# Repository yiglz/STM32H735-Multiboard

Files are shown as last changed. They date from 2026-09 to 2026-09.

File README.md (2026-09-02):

# STM32H735 Multiboard

Custom STM32H7-based embedded hardware platform designed for mixed-signal measurement and high-speed interfacing.

## Overview

This board combines a general-purpose embedded platform (Ethernet, USB HS, CAN-FD, local storage) with a precision analog front-end capable of impedance/frequency-response measurement. The idea was to have something that can act both as a data acquisition node and a small bench instrument on the same board.

## Features

- STM32H735 (Cortex-M7) MCU, 0.65mm pitch BGA
- 128Mbit SDRAM and 128Mbit QSPI NOR Flash, plus microSD for local storage and waveform logging
- 100BASE-T Ethernet (RMII), USB 2.0 HS (ULPI), and CAN-FD interfaces
- 16-bit, 4 MSPS simultaneous-sampling ADC front-end with protected, filtered, differentially-driven inputs
- Onboard DAC-driven excitation path with selectable reference resistors, forming a Bode analyzer / RLC impedance meter for characterizing an unknown DUT
- Dual power input (DC-jack + USB Type-C) with automatic priority switching

## PCB Design

Routed with signal integrity and delay matching in mind, using values that stay within what's standard for essentially every PCB manufacturer(minimum 4mil trace width/spacing, 0.2mm via hole, 0.4mm pad). No via-in-pad, microvia, or buried/blind vias were used.

## Repository Contents

- [Schematic PDF](./Schematic_STM32H735Multiboard.pdf)
- [Gerbers](./GerberFiles)
- [Draftsman](./Draftsman_STM32H735Multiboard.pdf)

## Project Status

- Schematic: Complete
- PCB Design: Complete
- Firmware: Not started yet

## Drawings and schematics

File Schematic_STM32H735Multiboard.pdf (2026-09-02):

# Power Section

### Output: 3.3 V

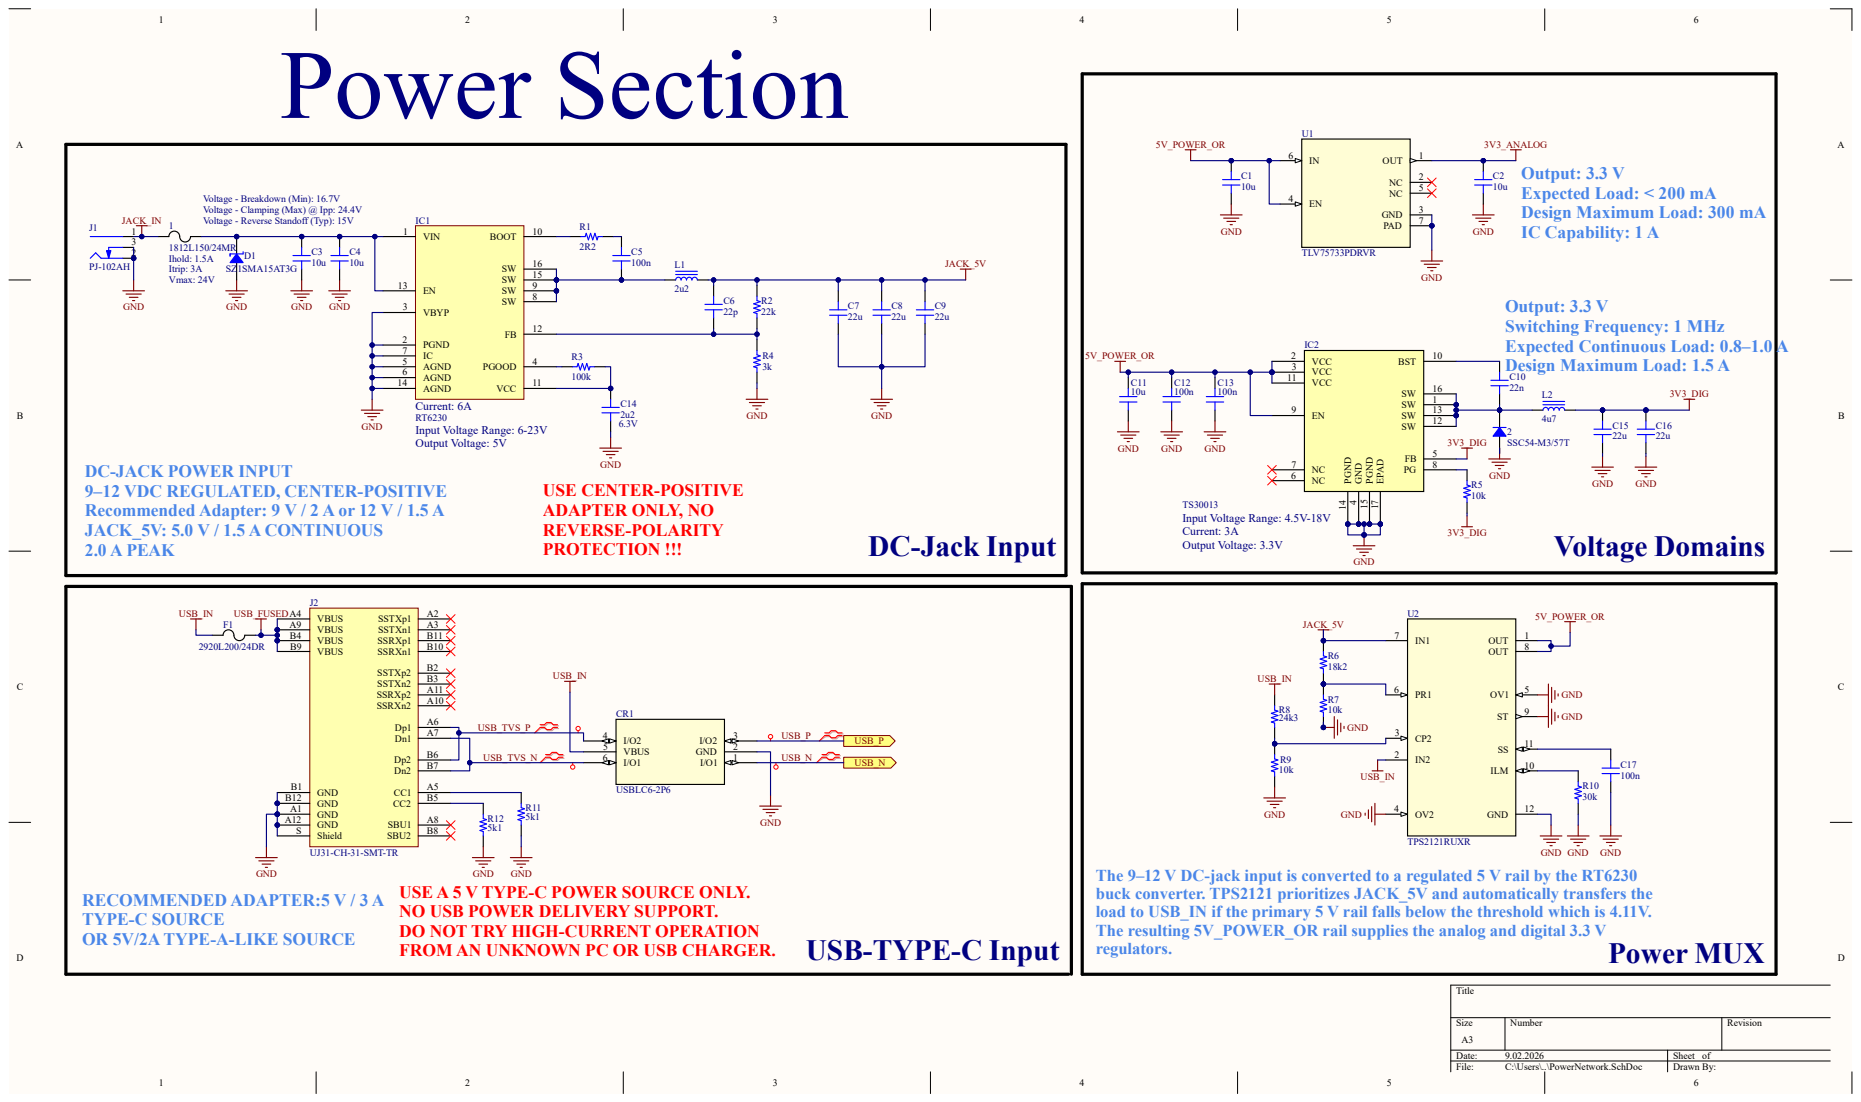
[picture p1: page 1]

Voltage - Breakdown (Min): 16.7V
Voltage - Clamping (Max) @ Ipp: 24.4V
Voltage - Reverse Standoff (Typ): 15V

DC-JACK POWER INPUT
9–12 VDC REGULATED, CENTER-POSITIVE
Recommended Adapter: 9 V / 2 A or 12 V / 1.5 A
JACK_5V: 5.0 V / 1.5 A CONTINUOUS
2.0 A PEAK

The 9–12 V DC-jack input is converted to a regulated 5 V rail by the RT6230
buck converter. TPS2121 prioritizes JACK_5V and automatically transfers the
load to USB_IN if the primary 5 V rail falls below the threshold which is 4.11V.
The resulting 5V_POWER_OR rail supplies the analog and digital 3.3 V
regulators.

USE A 5 V TYPE-C POWER SOURCE ONLY.
NO USB POWER DELIVERY SUPPORT.
DO NOT TRY HIGH-CURRENT OPERATION
FROM AN UNKNOWN PC OR USB CHARGER.

RECOMMENDED ADAPTER:5 V / 3 A
TYPE-C SOURCE
OR 5V/2A TYPE-A-LIKE SOURCE

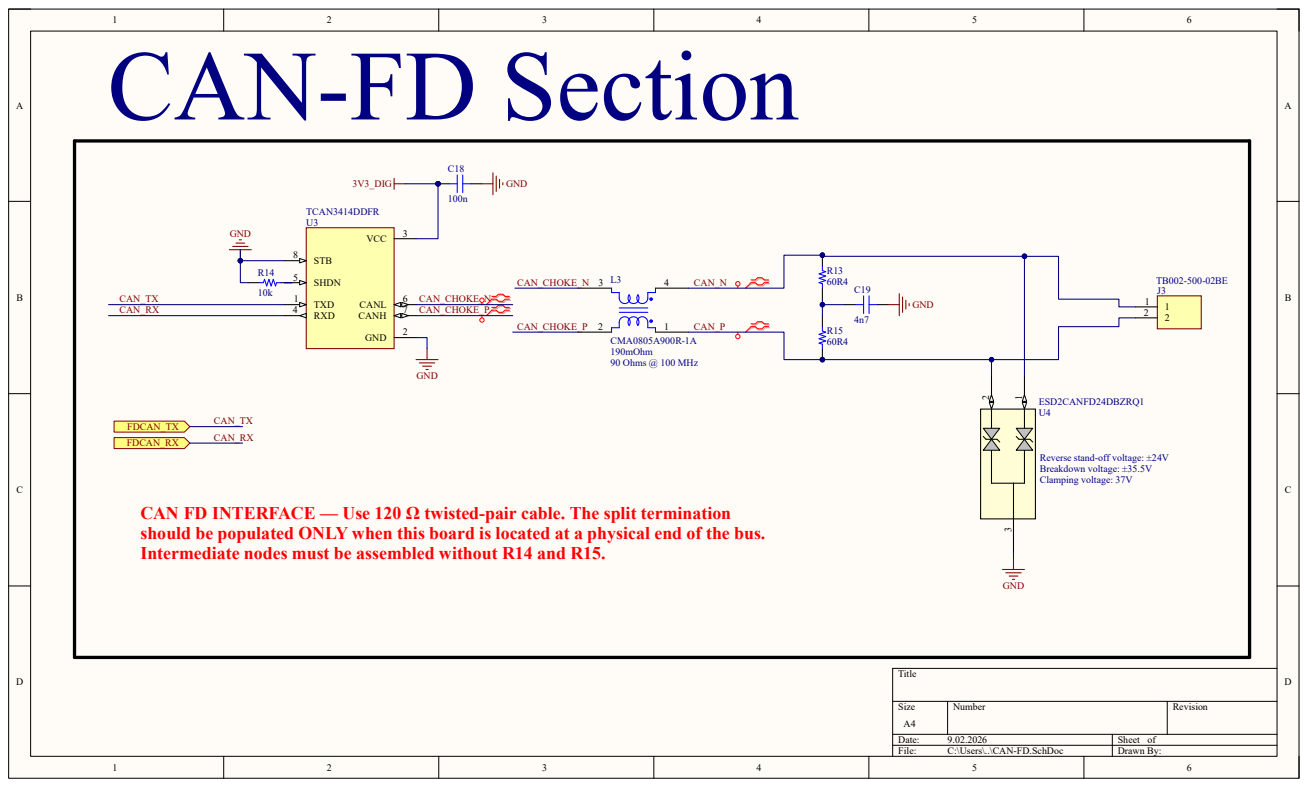
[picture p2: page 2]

Reverse stand-off voltage: ±24V
Breakdown voltage: ±35.5V
Clamping voltage: 37V

CAN FD INTERFACE — Use 120 Ω twisted-pair cable. The split termination
should be populated ONLY when this board is located at a physical end of the bus.
Intermediate nodes must be assembled without R14 and R15.

# 50 MHz Oscillator

# Ethernet Section

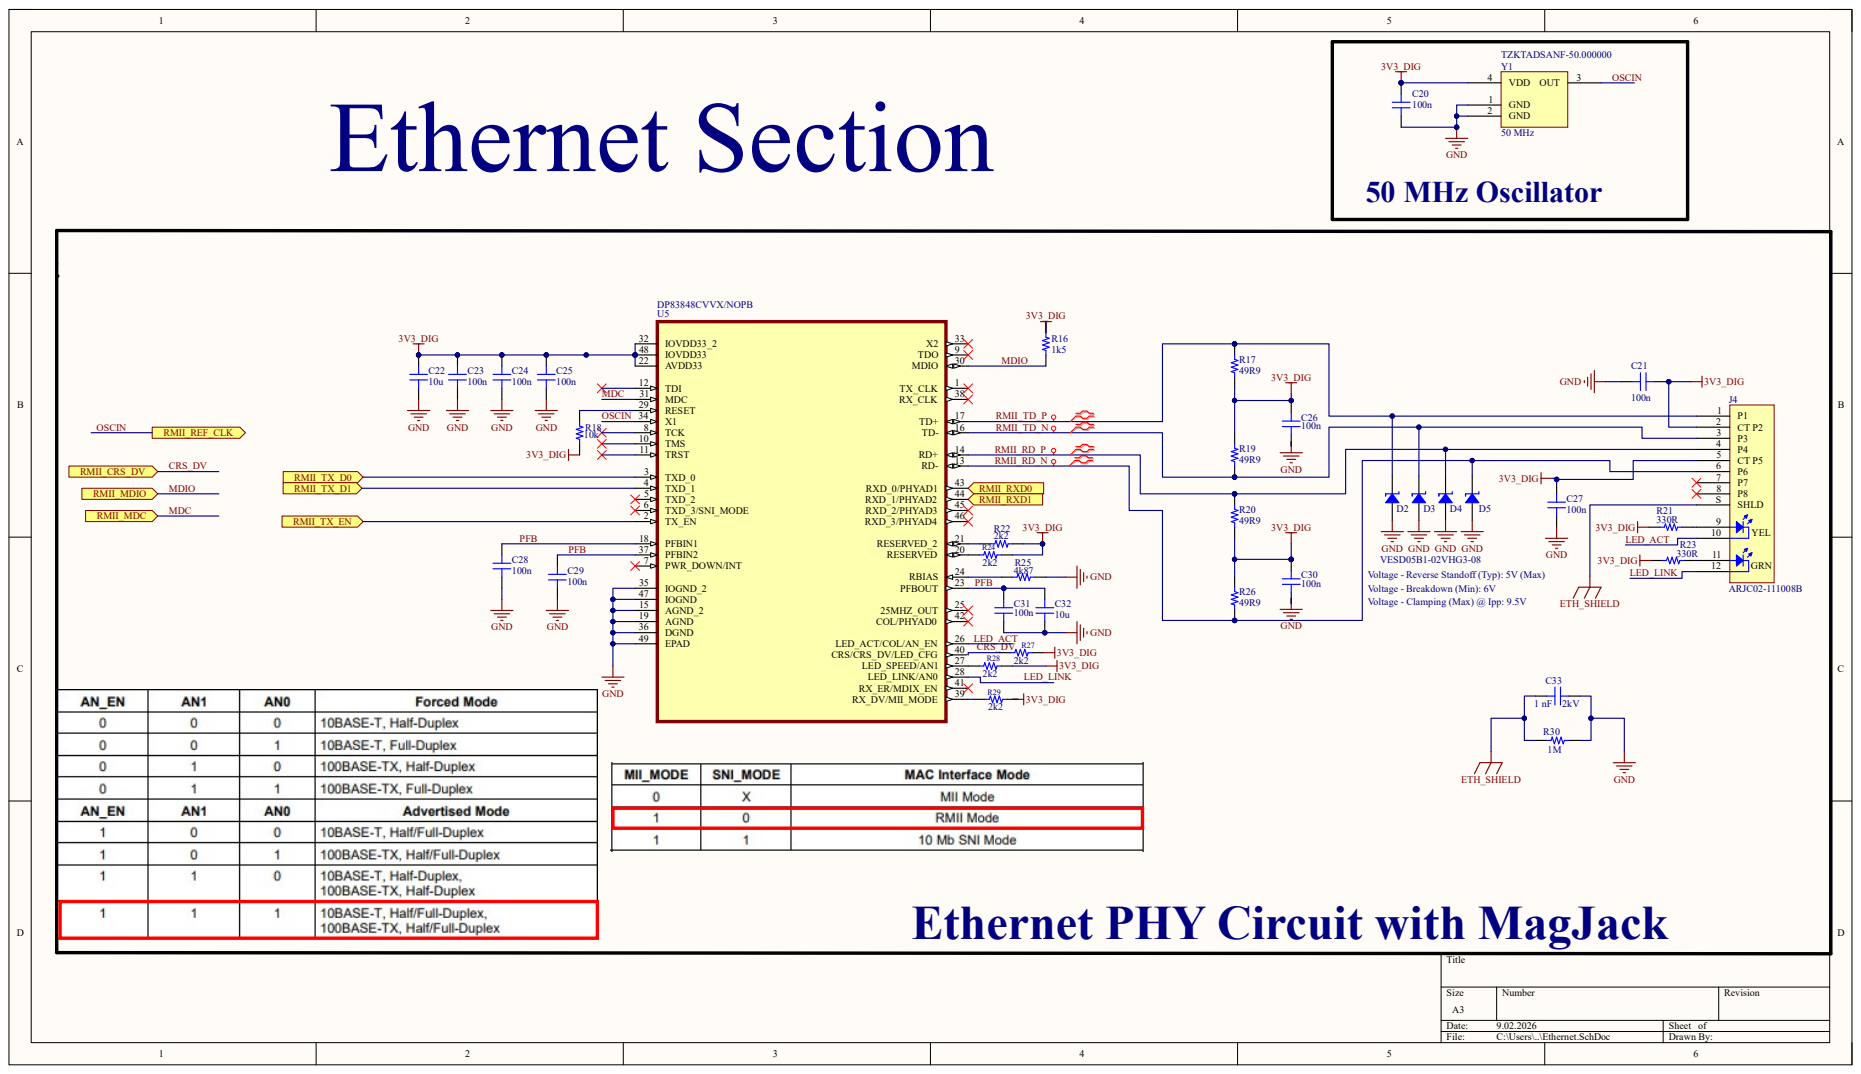
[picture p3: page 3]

GND GND
VESD05B1-02VHG3-08
Voltage - Reverse Standoff (Typ): 5V (Max)
Voltage - Breakdown (Min): 6V
Voltage - Clamping (Max) @ Ipp: 9.5V

Ethernet PHY Circuit with MagJack

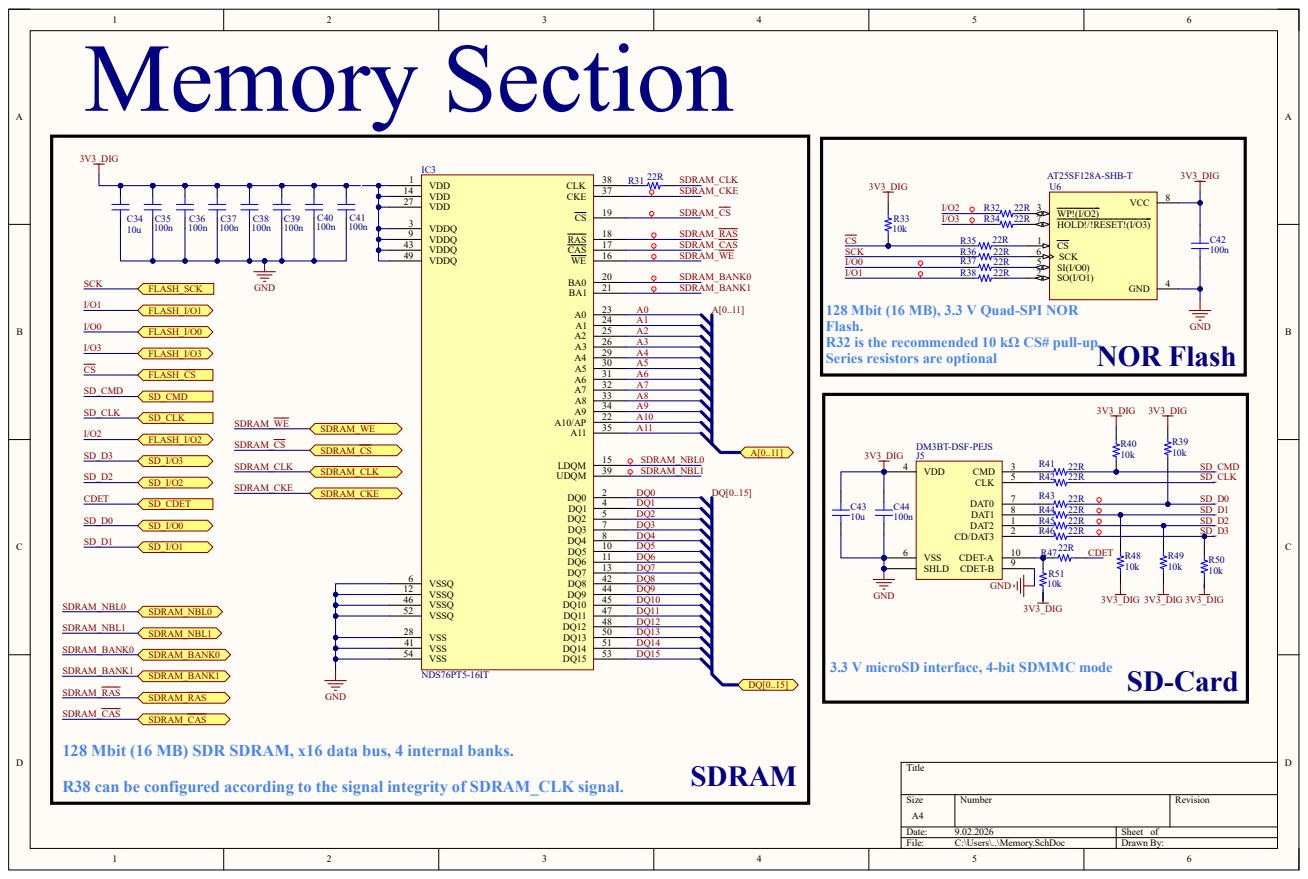
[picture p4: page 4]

128 Mbit (16 MB), 3.3 V Quad-SPI NOR
Flash.
R32 is the recommended 10 kΩ CS# pull-up.
Series resistors are optional

3.3 V microSD interface, 4-bit SDMMC mode

SDRAM_CAS
128 Mbit (16 MB) SDR SDRAM, x16 data bus, 4 internal banks.

R38 can be configured according to the signal integrity of SDRAM_CLK signal.

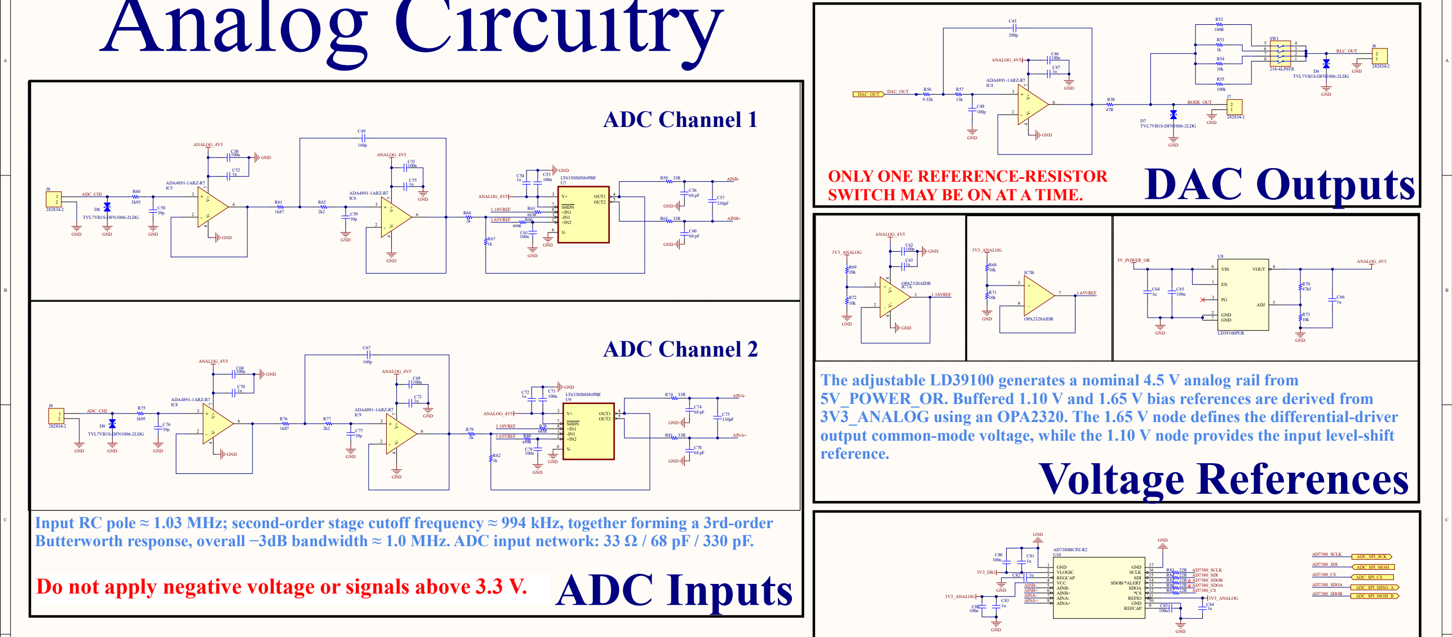
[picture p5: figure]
GND 1 VLOGIC 2 REGCAP 3 VCC 4 AINB- 5 AINB+ 6 AINA- 7 AINA+ 8; REFCAP; GND; 10 REFIO; 12 SDOA; 13 SDOB/*ALERT; 14 SDI; 15 SCLK; 16 GND; AD7380BCPZ-R2 V⁺; ADA4891-1ARZ-R7; TVL7VB1S-DFN1006-2LDG; SHDN 7 +IN1 8 -IN1 1 +IN2 2; OUT1; OUT2; LT6350IMS8#PBF; OPA2320AIDR; 3V3_ANALOG; 1.10VREF; 1.65VREF; R63 1.10VREF; AINA-; AINA+; 5V_POWER_OR; ADJ; VIN 6; GND 2 GND 7; VOUT; LD39100PUR; ANALOG_4V5; 3V3_DIG; AD7380_SCLK AD7380_SDI AD7380_SDOB AD7380_SDOA; AINB+; AINB-; ADC_CH1; ADC_CH2; DAC_OUT; D7 TVL7VB1S-DFN1006-2LDG; D6 TVL7VB1S-DFN1006-2LDG; RLC_OUT; BODE_OUT; ADC Inputs; ADC Channel 1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
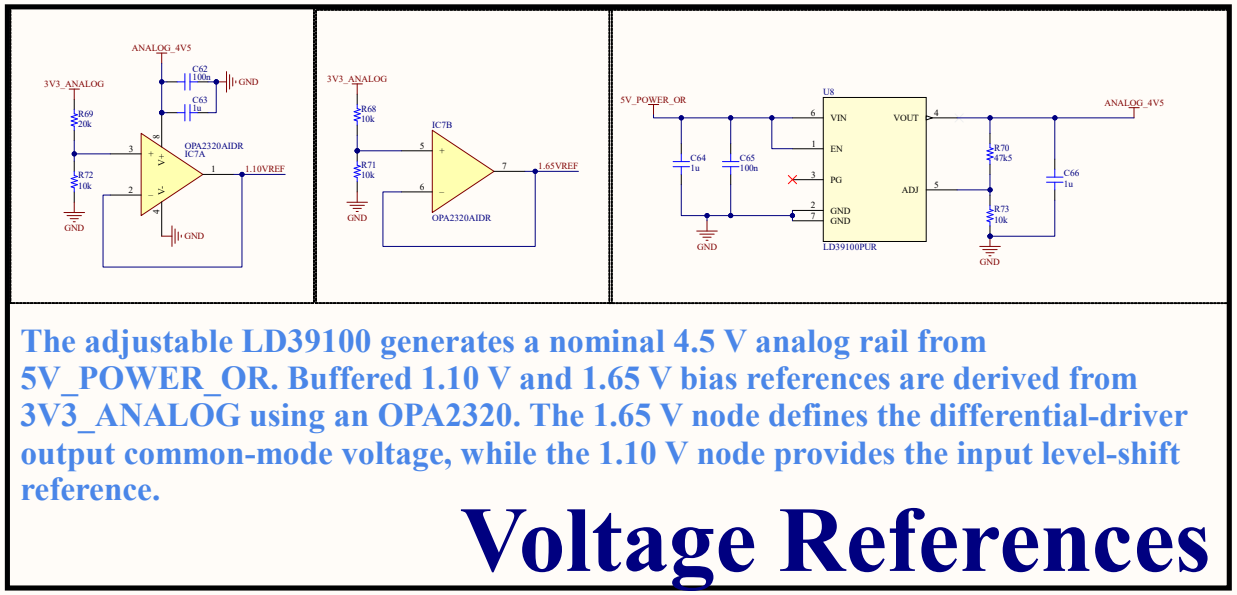
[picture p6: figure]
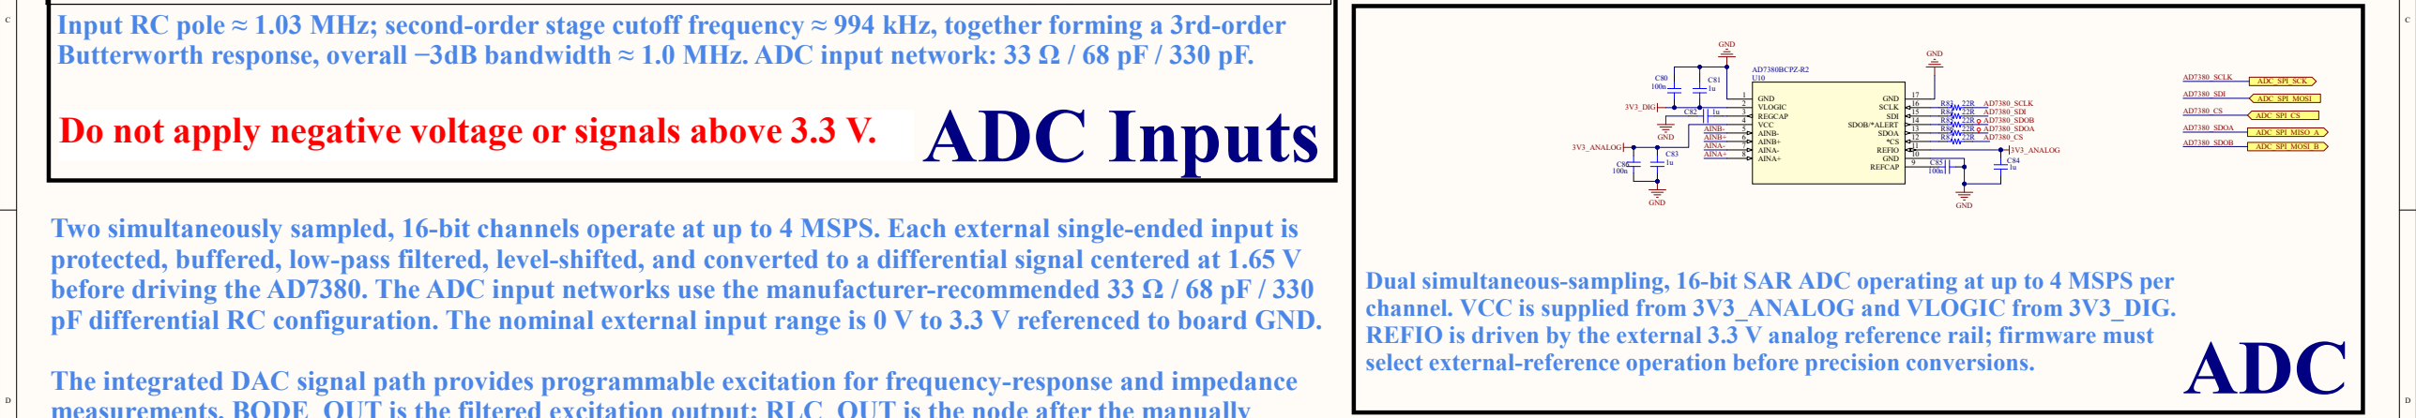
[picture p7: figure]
ADC

Title

Size | Number | Revision
A2
File: | C:\Users\..\AnalogCircuitry.SchDoc | Drawn By:

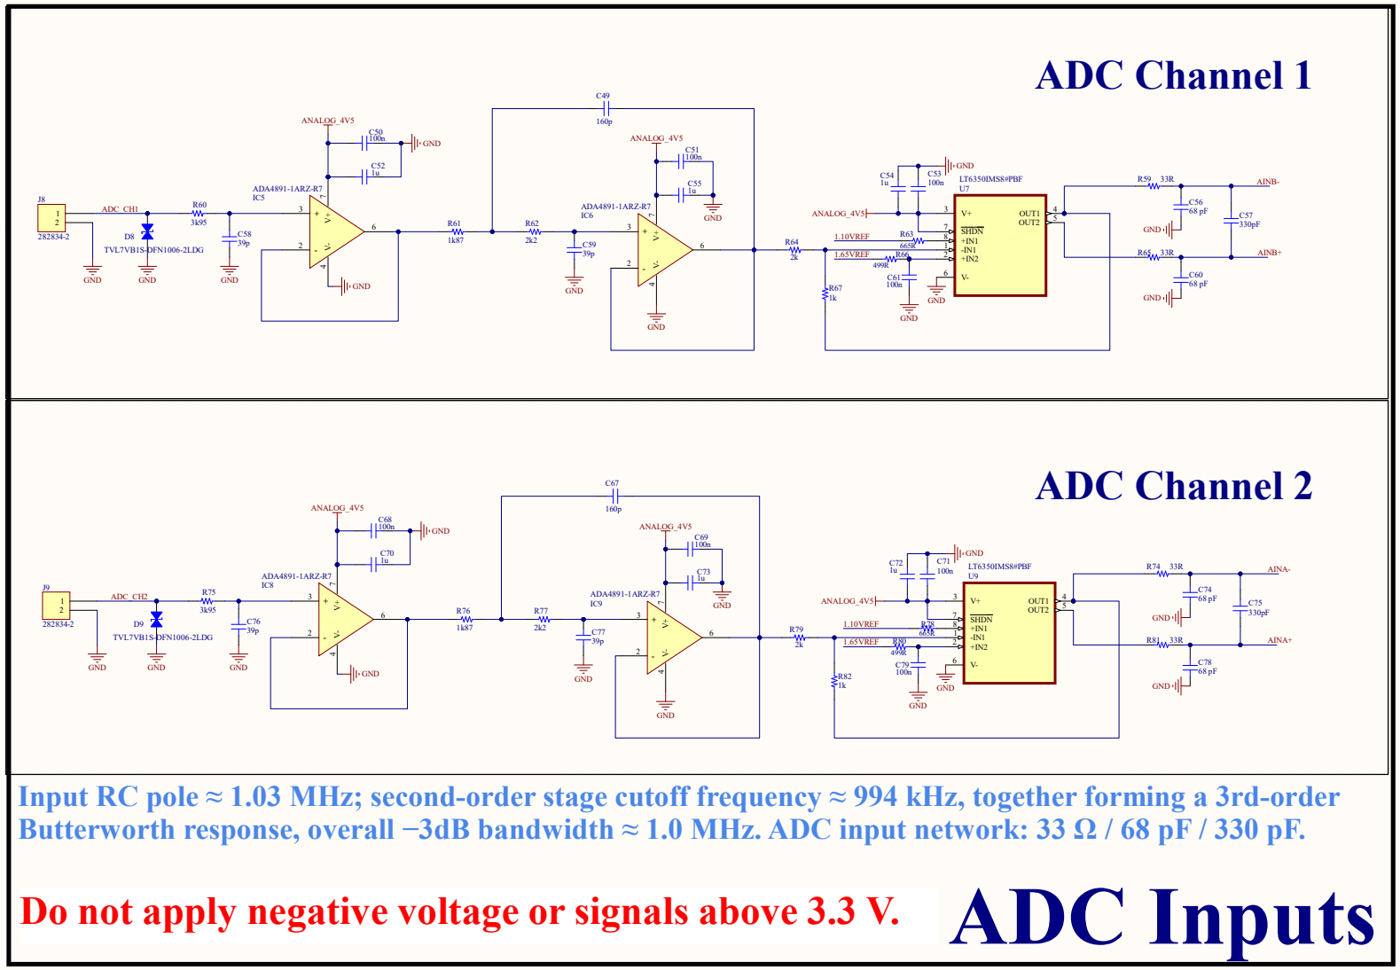
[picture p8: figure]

Two simultaneously sampled, 16-bit channels operate at up to 4 MSPS. Each external single-ended input is protected, buffered, low-pass filtered, level-shifted, and converted to a differential signal centered at 1.65 V before driving the AD7380. The ADC input networks use the manufacturer-recommended 33 Ω / 68 pF / 330 pF differential RC configuration. The nominal external input range is 0 V to 3.3 V referenced to board GND.

The integrated DAC signal path provides programmable excitation for frequency-response and impedance measurements. BODE_OUT is the filtered excitation output; RLC_OUT is the node after the manually selected reference resistor. Select only one reference resistor at a time. External test equipment and the device under test must share board GND. The analog interfaces are not isolated and are not permanently 50 Ω terminated.

Input RC pole ≈ 1.03 MHz; second-order stage cutoff frequency ≈ 994 kHz, together forming a 3rd-order Butterworth response, overall −3dB bandwidth ≈ 1.0 MHz. ADC input network: 33 Ω / 68 pF / 330 pF.
Do not apply negative voltage or signals above 3.3 V.

## The adjustable LD39100 generates a nominal 4.5 V analog rail from 5V_POWER_OR. Buffered 1.10 V and 1.65 V bias references are derived from 3V3_ANALOG using an OPA2320. The 1.65 V node defines the differential-driver output common-mode voltage, while the 1.10 V node provides the input level-shift

## Dual simultaneous-sampling, 16-bit SAR ADC operating at up to 4 MSPS per

channel. VCC is supplied from 3V3_ANALOG and VLOGIC from 3V3_DIG.
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

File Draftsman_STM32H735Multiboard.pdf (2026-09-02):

# Realistic View

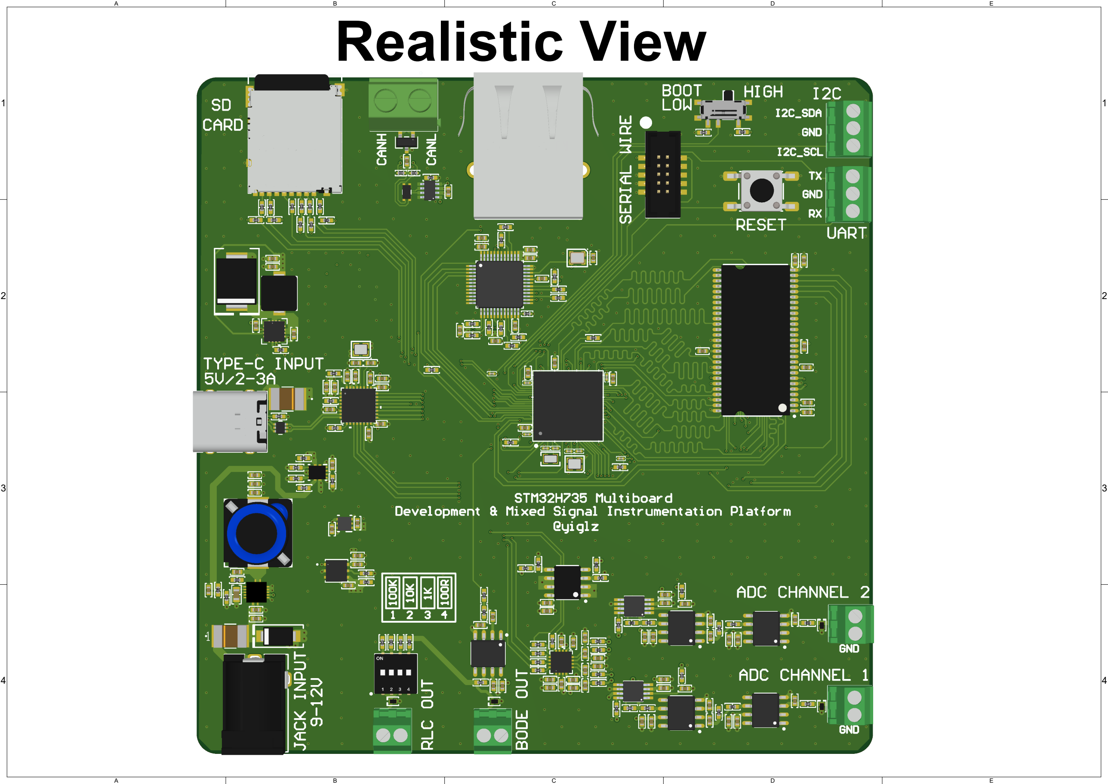
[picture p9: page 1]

A

B

C

D

E

1 | 1
2 | 2
3 | 3
4 | 4

# Realistic View

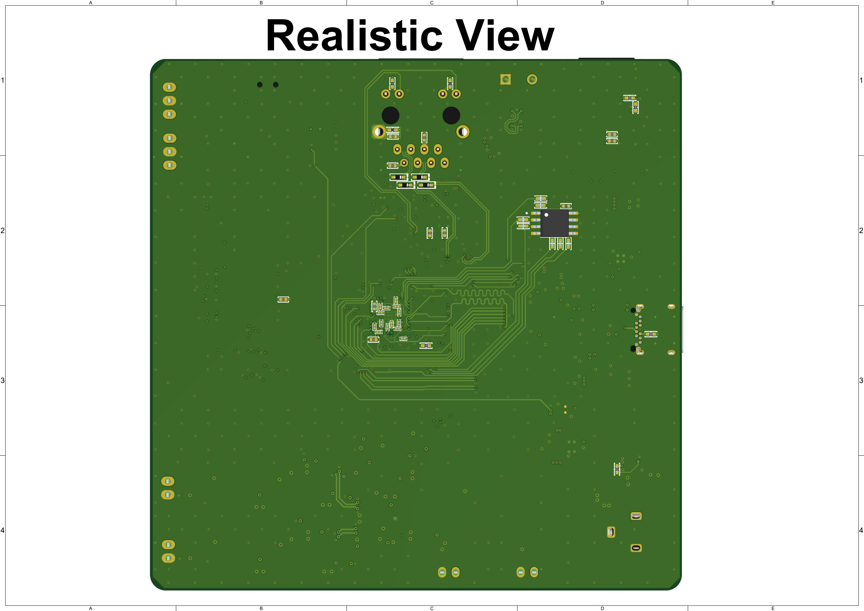
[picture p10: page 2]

1 | 1
2 | 2
3 | 3
4 | 4

# View from Top side (Scale 2.5:1)

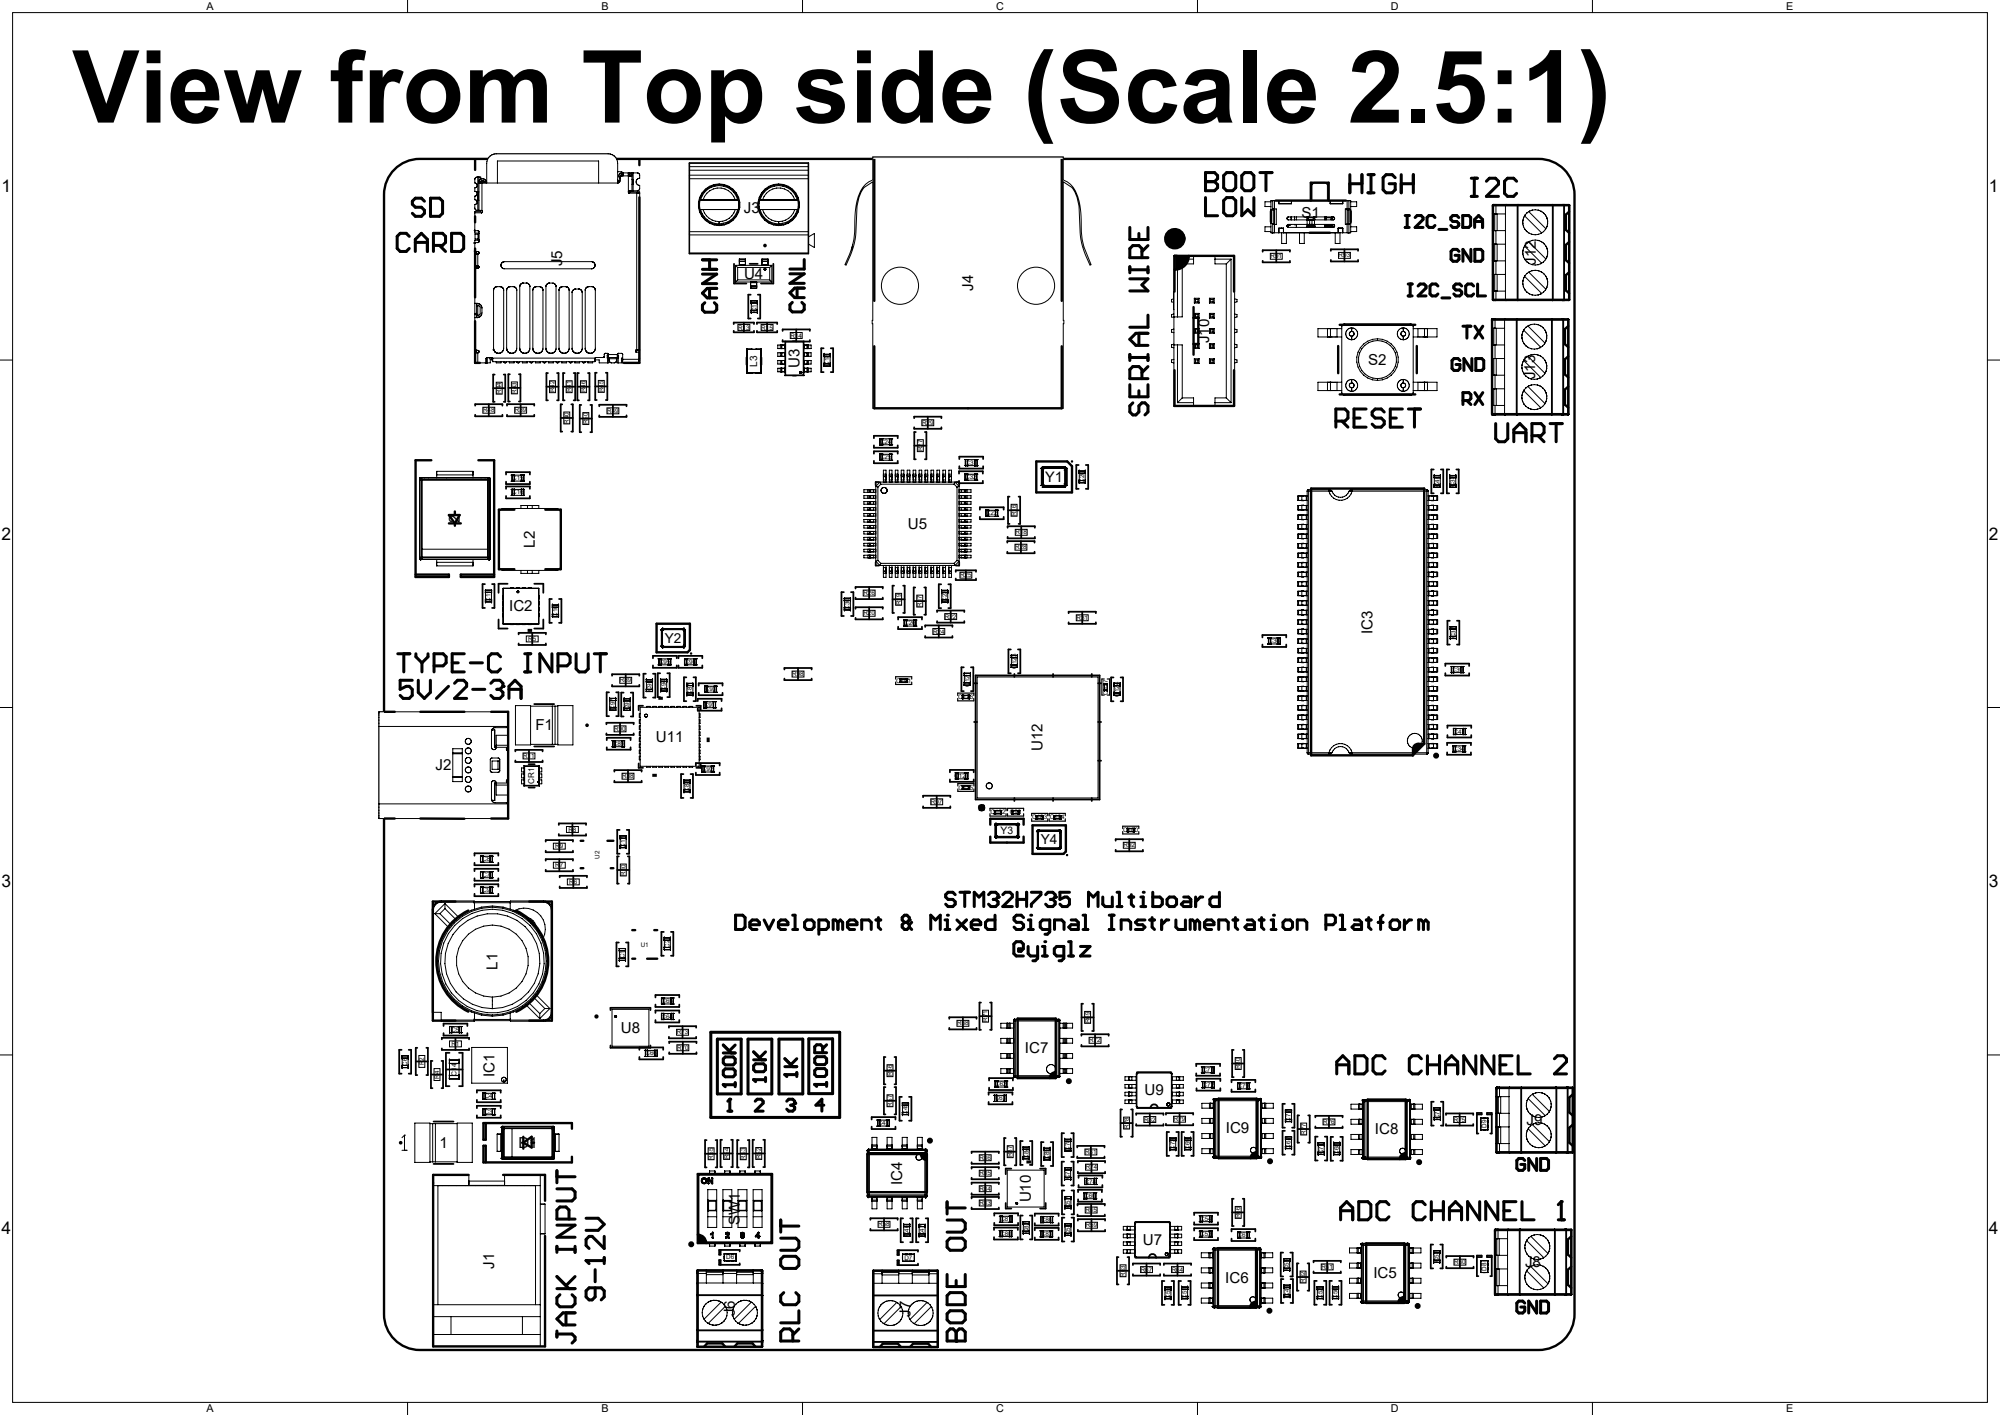
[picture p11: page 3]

# View from Bottom side (Scale 2.5:1) 100.00mm

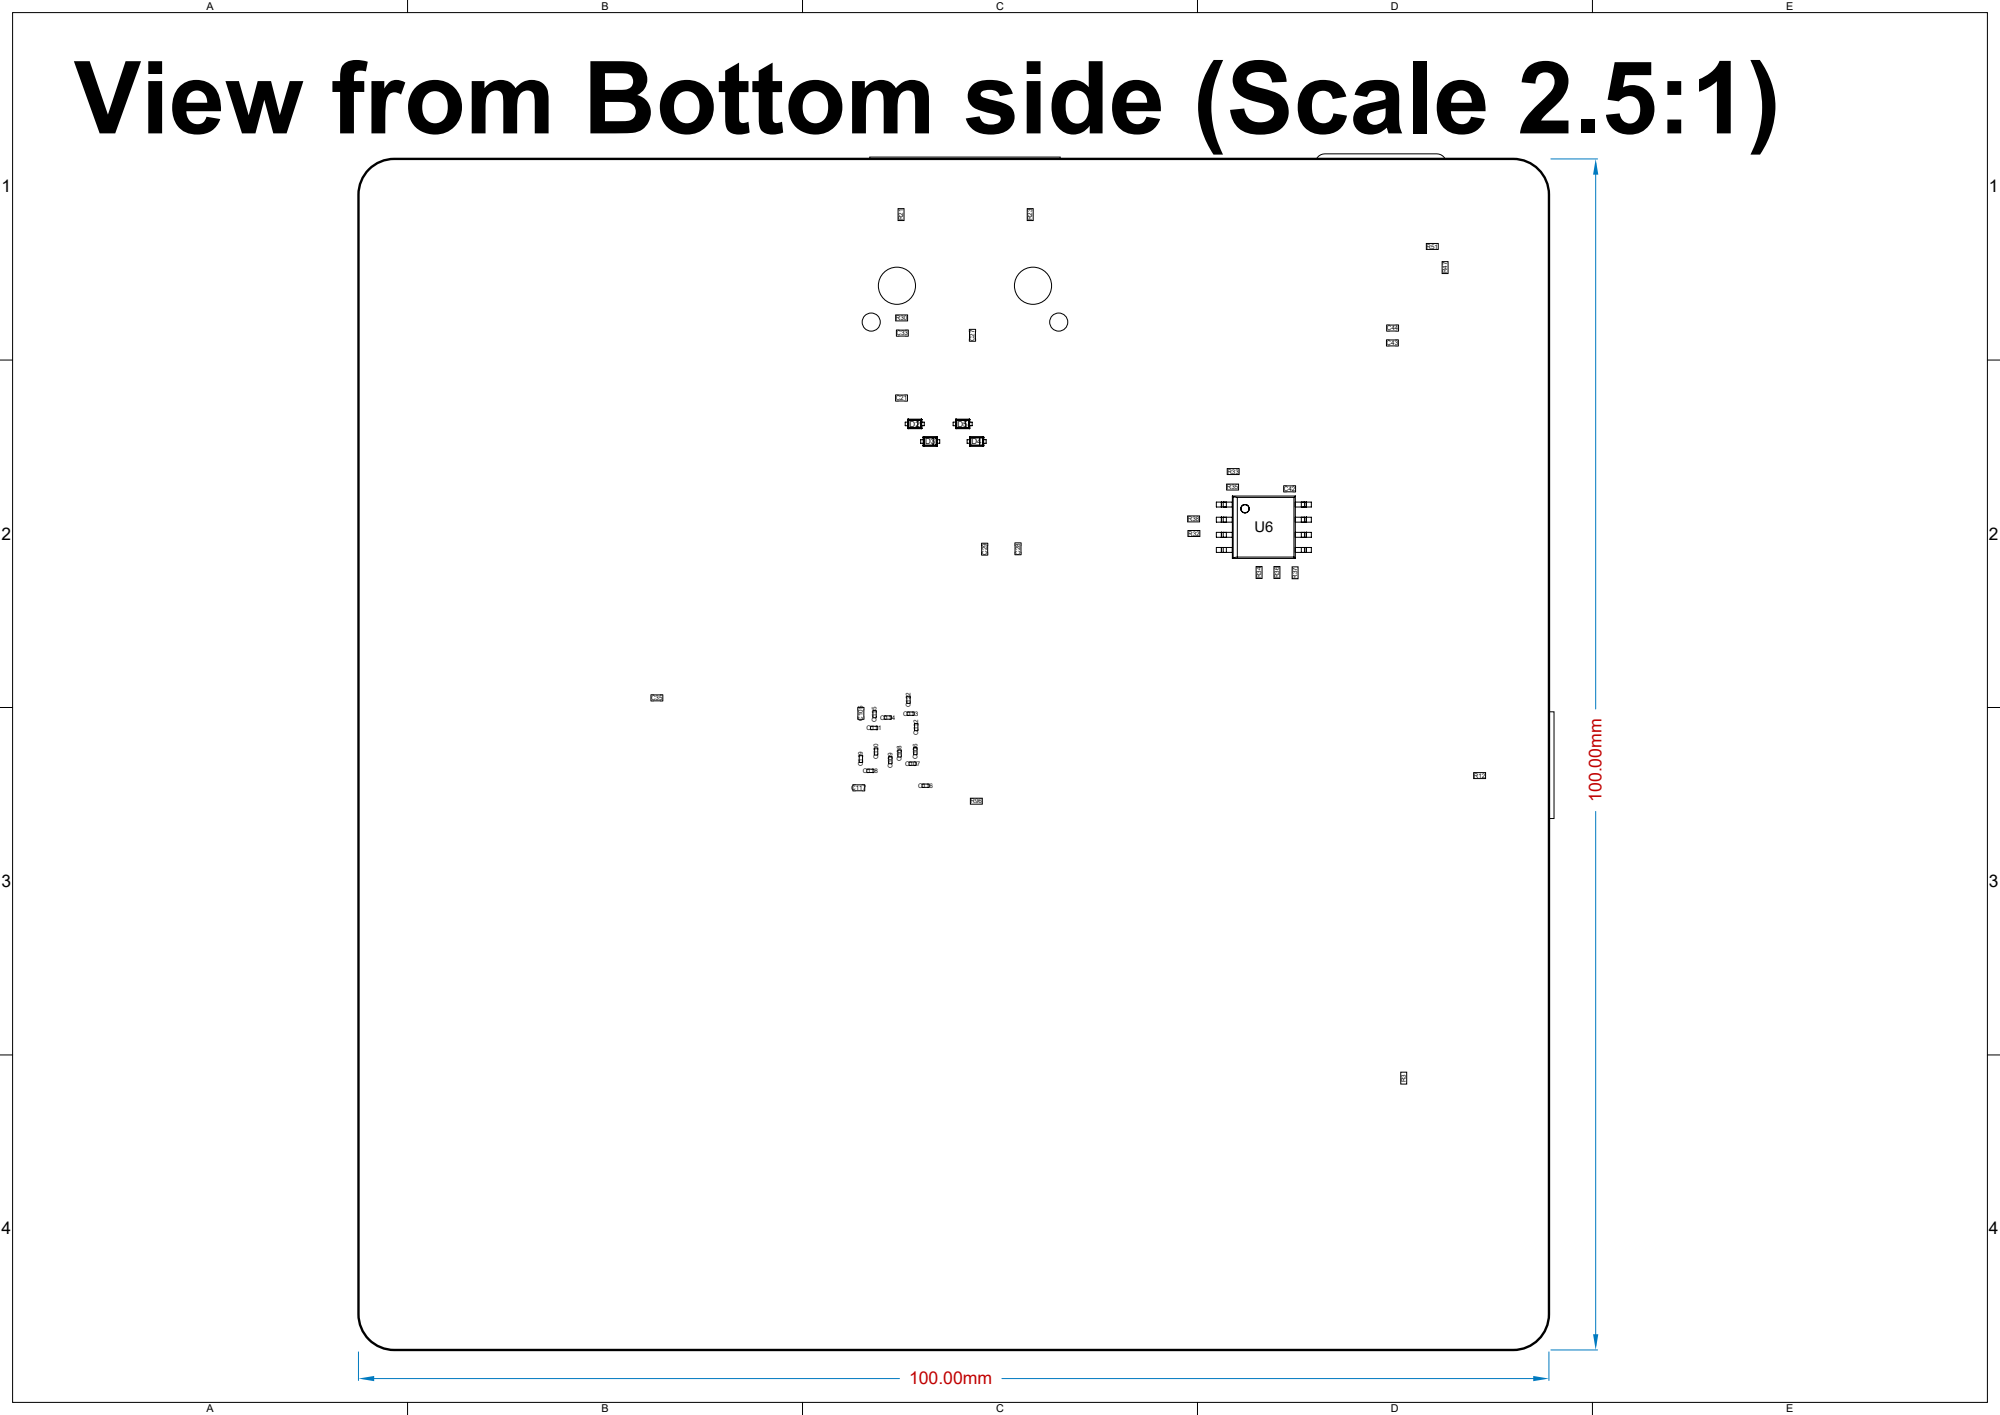
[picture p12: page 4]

# View from Front side (Scale 2:1)

View from Left side (Scale 2:1) ¹⁰.00mm

View from Back side (Scale 2:1)
View from Right side (Scale 2:1)

# Layer Stack Legend

Material; Layer; Thickness Dielectric Material Type; Gerber; Top Overlay; Legend; GTO; Surface Material Top Solder; Solder Resist; Solder Mask GTS; Copper; SIG1; Signal; GTL; Prepreg; Dielectric; GND1; Core; PWR; SIG2; GND2; SIG3; GBL; Surface Material Bottom Solder 0.01mm; Solder Mask GBS; Bottom Overlay; GBO; Total thickness: 1.65mm

# SIG1 (Scale 2.5:1)


# GND1 (Scale 2.5:1)


# PWR (Scale 2.5:1)


# SIG2 (Scale 2.5:1)


# GND2 (Scale 2.5:1)


# SIG3 (Scale 2.5:1)


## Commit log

2026-08-20 Schematic files are added.
2026-09-02 Deleted the old Schematic
2026-09-02 Add files via upload
    Schematic PDF has been added.
2026-09-02 Created Gerber Files folder
2026-09-02 Gerber Files have been added.
    [STM32H7_PCB_Copper_Signal_1.gbr, STM32H7_PCB_Copper_Signal_2.gbr, STM32H7_PCB_Copper_Signal_3.gbr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]
2026-09-02 Added fixed Schematic PDF
